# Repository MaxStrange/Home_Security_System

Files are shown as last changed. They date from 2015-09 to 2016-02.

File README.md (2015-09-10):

# Home_Security_System
A security system for my home!

This is a security system I am making for my home. It will consist of several wireless Arduino Pro Minis acting as sensor nodes
using PIR motion sensors, magnetic switches, a siren, microphones, and maybe an RF ID reader as the arm/disarm mechanism.

Uses tmrh20's fork of ManiacBug's NRF library for the wireless mechanisms (since XBee is so super expensive).

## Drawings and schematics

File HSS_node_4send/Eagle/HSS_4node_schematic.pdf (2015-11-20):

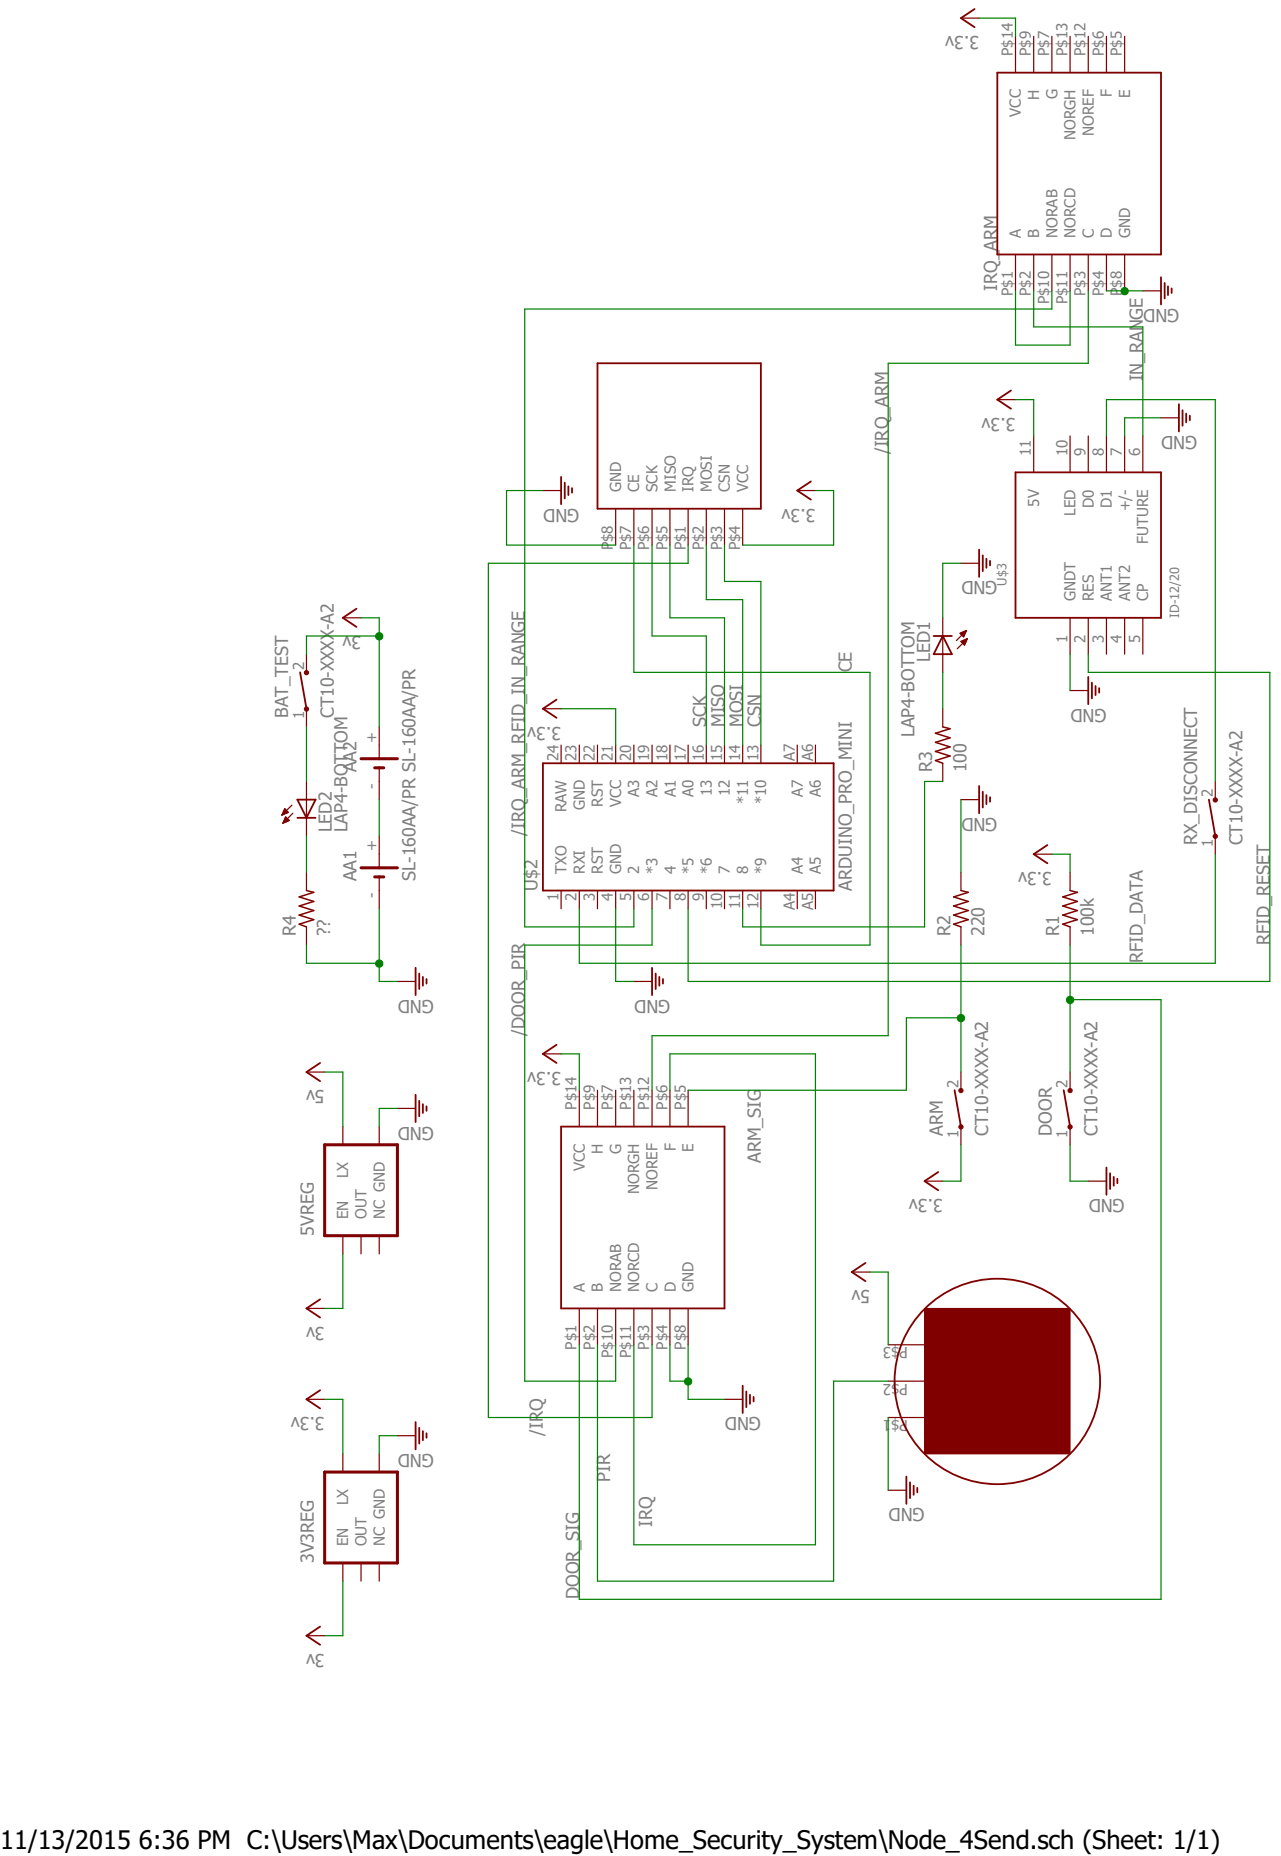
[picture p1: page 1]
8 11 *9 12 *10 13 *11 14 12 15 13 16 A0 17 A1 18 A2 19 A3 20 GND; 1 VCC 21 A7 A7 A6 A6 A4 A4 A5 A5 U$3 GNDT 1 RES; 2 ANT1; 3 ANT2; 5 FUTURE

F P$6 NOREF P$12 NORGH P$13 G P$7 H P$9 VCC P$14 LED2 R4 BAT_TEST 1 2 R3 LED1 RX_DISCONNECT 1 2 DOOR_SIG CE SCK MISO MOSI CSN /IRQ IRQ PIR ARM_SIG /DOOR_PIR /IRQ_ARM IRQ_ARM IN_RANGE /IRQ_ARM_RFID_IN_RANGE RFID_DATA RFID_RESET

A P$1 B P$2 NORAB P$10 NORCD P$11 C P$3 D P$4 GND P$8 E P$5

9 LED 10 5V 11 ARM 1 2 DOOR 1 2 R2R1

F P$6 NOREF P$12 NORGH P$13 G P$7 H P$9 VCC P$14 VCC P$4 CSN P$3 MOSI P$2 IRQ P$1 MISO P$5 SCK P$6 CE P$7 GND P$8

11/13/2015 6:36 PM C:\Users\Max\Documents\eagle\Home_Security_System\Node_4Send.sch (Sheet: 1/1) SL⁻160AA/PR SL⁻160AA/PR

4 GND 23 RAW 24 RST

3 RST 22 RXI 2 TXO

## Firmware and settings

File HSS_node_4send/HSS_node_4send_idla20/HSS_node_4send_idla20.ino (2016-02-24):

/**
This is the 4send node. It is the node responsible for sending
the arm/disarm signal to the rest of the nodes. It also has
sensor (PIR and magnetic switch) through a NOR gate (so they
are active low).

It sleeps until an interrupt on pin 2 wakes it. Pin 2 could
be one of three things: the RFID has sensed a tag in range,
the nRF has sent an IRQ (probably because it received a 
signal), and/or the arm button was pushed. It first checks
its nRF module to see if that was what woke it. If it was, and
it received an arm signal (which is impossible until I get
a raspberry pi online), it arms itself (sets up an interrupt
from the sensors on pin 3) and goes back to sleep. Whether or
not it was the nRF that woke it, it also checks to see if
the RFID module has a card waiting to be read. If it does,
it reads the card and, if the card is one of the known ones,
it disarms itself and broadcasts the disarm signal. If neither
of these things was what woke it from sleep, it must have
been the arm signal. If it was, it broadcasts the arm signal
and arms itself (puts the sensor interrupt on pin 3) and
goes back to sleep.

Once armed, it sleeps until woken up by either an interrupt
on pin 2 (in which case, see above) or an interrupt on pin 3,
in which case it has sensed an intruder and it therefore sends
a threat signal to the accumulator node. Once it has sent
this message and it is reasonably sure it has been heard, it
will not send its threat signal again until disarmed and 
re-armed or a power cycle happens.
*/
#include <avr/interrupt.h>
#include <avr/power.h>
#include <avr/sleep.h>
#include <avr/io.h>
#include <SPI.h>
#include "RF24.h"

/**Constants**/
const unsigned int SECONDS_TO_CLEAR_AREA = 30;//The number of seconds the system will give people to clear the area before arming after the arm button has been pushed
const unsigned int TIMES_TO_SEND = 6;//The number of times to try to send a signal before giving up
const unsigned int MAX_TIMES_TO_SEND_SIGNAL = 15;//The maximum number of times to send the threat signal to the accumulator per disarm/arm cycle
const uint16_t THREAT_SIGNAL = 0x1BA0;
const uint16_t DISARM_SIGNAL = 0x1151;
const uint16_t ARM_SIGNAL = 0x1221;

/**Pin declarations**/
const int SENSORS = 3;//Mag switch NOR'd with a PIR signal
const int LED = 8;
const int RADIO_PIN_1 = 9;
const int RADIO_PIN_2 = 10;

/**Radio code**/
RF24 radio(RADIO_PIN_1, RADIO_PIN_2);
//Accumulator and four other nodes. Node 4send is the arm/disarm node. The fifth is a private channel from node4 to accmltr
byte node_ids[][6] = { "cmltr", "1send", "2send", "3send", "4send" , "5send" };

/**RFID code**/
const int KEY_LENGTH = 16;
char key_a[KEY_LENGTH] = { 63, 100, 94, 230, 166, 102, 230, 76, 102, 166, 201, 201, 202, 214, 242, 0 };
char key_b[KEY_LENGTH] = { 63, 100, 94, 230, 166, 102, 166, 76, 153, 166, 76, 153, 202, 214, 242, 0 };
char key_c[KEY_LENGTH] = { 63, 100, 94, 230, 166, 166, 204, 151, 204, 201, 62, 234, 202, 214, 242, 0 };
char incoming_key[KEY_LENGTH] = { 0,0,0,0,0,0,0,0,0,0,0,0,0,0,0,0 };
String input_string = "";

/**State**/
volatile boolean disarm_flag = false;
volatile boolean rfid_flag = false;
volatile boolean arm_switch_flag = false;
volatile boolean arm_signal_heard_flag = false;
volatile boolean system_is_armed = false;
volatile unsigned int sent_signal_times = 0;//Number of times this node has sent the threat signal to the accumulator 
unsigned int arm_button_held_down_count = 0;//Duration that the arm button has been held for

void setup(void)
{  
  /**Pins**/
  pinMode(SENSORS, INPUT);
  pinMode(LED, OUTPUT);
  
  /**Radio**/
  radio.begin();
  radio.setRetries(15, 15);//Retry 15 times with a delay of 15 microseconds between attempts
  radio.openWritingPipe(node_ids[4]);//open up a broadcasting pipe - all other nodes listen to this pipe
  
  /**RFID**/
  Serial.begin(9600);
  input_string.reserve(20);
}

void loop(void)
{
  serialEvent();
  
  if (rfid_flag)
  {//check if there is rfid data waiting on serial
    Serial.println("RFID flag.");
    if (check_rfid())
    {
      disarm_flag = true;
      arm_switch_flag = false;
      arm_button_held_down_count = 0;
      Serial.println("known key");
    }
    //now flush the rfid so that it doesn't contain any leftover data
    input_string = "";
    Serial.println("Input buffer flushed.");
    rfid_flag = false;//clear the flag
    Serial.println("RFID flag cleared.");
  }
  
  if (disarm_flag)
  {//disarm the system - broadcast the disarm signal and then disarm
    Serial.println("Disarm flag.");
    disarm_system();
    disarm_flag = false;//clear the flag
    digitalWrite(LED, HIGH); 
    Serial.println("Disarm flag cleared.");
  }
  
  if (arm_switch_flag)
  {//arm the system - broadcast the arm signal and then arm yourself
    Serial.println("Arm switch flag.");
    arm_switch_flag = false;//clear the flag
    
    if (check_rfid())
    {
      Serial.println("Key is present.");
    }
    else
    {
      if (!system_is_armed)
        arm_button_held_down_count++;
        
      Serial.print("Arm button held: "); Serial.println(arm_button_held_down_count);
      
      if ((arm_button_held_down_count >= 5) && (!system_is_armed))
        arm_system();
    }
    
    Serial.println("Arm switch flag cleared.");
  }
  
  if (arm_signal_heard_flag)
  {//arm this particular node - the system has been broadcasted to already by the rPi
    Serial.println("Arm signal heard flag.");
    arm_signal_heard_flag = false;//clear the flag
    arm_self();
    Serial.println("Arm signal heard flag cleared.");
  }
  
  //All done with work that needed to be done. Put the RFID/nRF/Arm_switch interrupt back on and go to sleep.
  Serial.println("Sleep.");
  delay(500);
  digitalWrite(LED, LOW);
  attachInterrupt(0, arm_disarm_ISR, LOW);
  go_to_sleep();
}

void arm_disarm_ISR(void)
{
  detachInterrupt(0);//Don't interrupt again until flags have been dealt with - this should also serve to debounce the arm switch
  detachInterrupt(1);
  
  /**First, make sure to check the RFID**/
  rfid_flag = true;
  
  /**Now check the radio**/
  bool tx, fail, rx = false;
  radio.whatHappened(tx, fail, rx);
    
  /**If rx, get what we received**/
  uint8_t reading_pipe_number;
  if (rx && radio.available(&reading_pipe_number))
  {
    uint16_t signal;
    radio.read(&signal, sizeof(uint16_t));
    
    if (signal == DISARM_SIGNAL)
      disarm_flag = true;
    else if (signal == ARM_SIGNAL)
      arm_signal_heard_flag = true;
  }
  
  /**If not rx, was it the radio? 
  If so, don't care. But if it wasn't, 
  then it MIGHT have been the arm switch.**/
  if (!fail && !tx)
    arm_switch_flag = true;//if it wasn't the software serial, it was the arm switch - check that later
}

void sensor_ISR(void)
{
  if (sent_signal_times < MAX_TIMES_TO_SEND_SIGNAL)
  {
    detachInterrupt(0);
    detachInterrupt(1);
    Serial.println("sensor detected something. Sending threat.");
    //If this ISR is fired, it is because we are armed and either the mag switch is open or the PIR saw something
    radio.stopListening();
    radio.openWritingPipe(node_ids[5]);//open the private channel between this node and the accumulator
    if (write_to_radio(&THREAT_SIGNAL, sizeof(uint16_t)))
      sent_signal_times++;
    radio.openWritingPipe(node_ids[4]);//reopen the broadcast channel - close the other channel
    attachInterrupt(0, arm_disarm_ISR, LOW);
    attachInterrupt(1, sensor_ISR, LOW);
  }
  else
  {//we have already bugged the accumulator enough - it probably heard us by now, so let's just stop trying
    detachInterrupt(1);
  }
}

void arm_self(void)
{
  Serial.println("Arm self.");
  
  system_is_armed = true;
  attachInterrupt(1, sensor_ISR, LOW);//arm yourself too
}

void arm_system(void)
{
  Serial.println("Arm system.");
  arm_button_held_down_count = 0;
  digitalWrite(LED, HIGH); 
  
  /*Delay for how ever many seconds, checking for a key every second*/
  boolean do_not_arm = false;
  for (int i = SECONDS_TO_CLEAR_AREA; i > 0; i--)
  {
    Serial.print("Countdown: "); Serial.println(i);
    delay(1000);
  }
  
  if (!do_not_arm)
  {
    broadcast_signal(ARM_SIGNAL);
    arm_self();
  }
}

void disarm_system(void)
{
  detachInterrupt(1);//detach sensor ISR
  Serial.println("Disarm system.");
  broadcast_signal(DISARM_SIGNAL);
  system_is_armed = false;
  sent_signal_times = 0;
}

void broadcast_signal(uint16_t signal)
{
  Serial.println("Broadcast signal.");
  radio.stopListening();
  write_to_radio(&signal, sizeof(uint16_t));
}

void go_to_sleep(void)
{
  set_sleep_mode(SLEEP_MODE_IDLE);
  //set_sleep_mode(SLEEP_MODE_STANDBY);//standby works - but no deeper - only takes 6 clock cycles to boot back up
  sleep_enable();
  sleep_mode();
}

boolean write_to_radio(const void * to_write, uint8_t len)
{
  Serial.println("Write to radio.");
  
  for (int i = 0; i < TIMES_TO_SEND; i++)
  {
    Serial.print("Write: "); Serial.println(i);
    if (radio.write(to_write, len))//This is the line that is buggy. It hangs here eventually, but only when trying to disarm the system. And not necessarily on the first call to this from the disarm.
    {
      return true;
    }
    
    delay(10);
  }
  
  Serial.println("Returning false.");
  return false;
}

void serialEvent()
{
   while (Serial.available())
   {
     char inChar = (char)Serial.read();  
     input_string += inChar;
   }
   
   input_string.toCharArray(incoming_key, KEY_LENGTH);
}

boolean check_rfid()
{
   for (int i = 0; i < KEY_LENGTH; i++)
   {
     if ((incoming_key[i] != key_a[i]) && (incoming_key[i] != key_b[i]) && (incoming_key[i] != key_c[i]))
     {
       return false;
     }
   }
   
   return true;
}

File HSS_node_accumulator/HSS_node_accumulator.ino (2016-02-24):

/**
This is the accumulator sketch. It is the node that is responsible for sounding the alarm if the right sequence of events
happen as reported by the other sensor nodes. To save money and space, it is also a pir/switch sensor node.

It sounds the alarm if it receives a signal from two different nodes (including possibly itself). If it receives
a signal from a node, it enters the alert mode, whereupon it starts a countdown. If, within that countdown, it receives
a second signal (not from the same node), it enters intruder_detected mode and sounds the alarm. If it doesn't receive
the second signal within the alotted time, it resets back to all_clear mode.

If it enters intruder_detected mode, it will sound the alarm for several seconds, and wait for the disarm signal to come.
If it never gets the disarm signal, it eventually resets to all_clear.
*/
#include <avr/interrupt.h>
#include <avr/power.h>
#include <avr/sleep.h>
#include <avr/io.h>
#include <SPI.h>
#include "RF24.h"

/**Typedefs**/
typedef enum { ALL_CLEAR_MODE, ALERT_MODE, INTRUDER_DETECTED_MODE } alert_level_type;

/**Constants**/
const unsigned long ALARM_COUNTDOWN = 30000;//30,000 milliseconds (30 seconds)//The time the alarm sounds for
const unsigned long INTRUDER_COUNTDOWN = 20000;//20,000 milliseconds (20 seconds)//The amount of time to wait for a second threat signal before reset
const uint16_t THREAT_SIGNAL = 0x1BA0;
const uint16_t DISARM_SIGNAL = 0x1151;
const uint16_t ARM_SIGNAL = 0x1221;
const unsigned int NUMBER_OF_NODES = 5;//Number of nodes in the system including this one
const unsigned int TIME_TO_DISARM = 10000;//10,000 milliseconds (10 seconds)//The time you have to disarm the system before alarm

/**Pin declarations**/
const int SENSORS = 3;//PIR and Mag switch through a NOR gate - so LOW when bad guy detected
const int SPEAKER = 8;
const int RADIO_PIN_1 = 9;
const int RADIO_PIN_2 = 10;

/**Radio code**/
RF24 radio(RADIO_PIN_1, RADIO_PIN_2);
//Accumulator and four other nodes. Node 4send is the arm/disarm node. The fifth is a private channel from node4 to accmltr
byte node_ids[][6] = { "cmltr", "1send", "2send", "3send", "4send" , "5send" };

/**State**/
volatile boolean system_armed = false;
volatile alert_level_type danger_level = ALL_CLEAR_MODE;
volatile unsigned long countdown_timer = 0;
volatile boolean alert_from_node[] = { false, false, false, false, false };//Array of alerts from nodes in the system - node 0 is this node.
volatile boolean disarm_flag = false;
volatile boolean arm_system_flag = false;
boolean alarm_sounding = false;

void setup(void)
{
  /**Pins**/
  pinMode(SENSORS, INPUT);
  pinMode(SPEAKER, OUTPUT);
  
  /**Radio**/
  radio.begin();
  radio.setRetries(15, 15);//Retry 15 times with a delay of 15 microseconds between attempts
  radio.openReadingPipe(1, node_ids[1]);
  radio.openReadingPipe(2, node_ids[2]);
  radio.openReadingPipe(3, node_ids[3]);
  radio.openReadingPipe(4, node_ids[4]);//arm/disarm node broadcast channel
  radio.openReadingPipe(5, node_ids[5]);//private channel to arm/disarm node
  radio.startListening();
  
  attachInterrupt(0, check_messages_ISR, LOW);//Attach an interrupt on a LOW signal on Pin 2
  
  Serial.begin(115200);
}

void loop(void)
{ 
  digitalWrite(SPEAKER, HIGH);
  
  /*Go through the flags and deal with them*/
  if (disarm_flag)
  {
    disarm_flag = false;
    disarm();
  }
    
  if (arm_system_flag)
  {
    arm_system_flag = false;
    system_armed = true;
    attachInterrupt(1, sensor_ISR, LOW);
  }
  
  if (! system_armed)
  {
    Serial.println("System not armed, so going to sleep.");
    delay(1000);
    //Just go to sleep until the system is armed
    set_sleep_mode(SLEEP_MODE_PWR_DOWN);
    sleep_enable();
    sleep_mode();
  }
  
  adjust_threat_level();
  
  /**Manipulate countdown timer and adjust mode accordingly**/
  if (countdown_timer > ALARM_COUNTDOWN)
  {//Timer has wrapped around for some reason, reset it.
    Serial.println("Countdown timer has wrapped around. This shouldn't have happened.");
    Serial.print("Timer: "); Serial.println(countdown_timer);
    countdown_timer = 0;
  }
  else if (countdown_timer > 0)
  {
    for (int i = 0; i < 5; i++)
    {
      Serial.print("Node "); Serial.print(i); Serial.print(" "); Serial.println(alert_from_node[i] ? "true" : "false");
    }
  
    Serial.print("Counting down: "); Serial.println(countdown_timer);
    countdown_timer -= 1000;
  }
  else if (! (disarm_flag || arm_system_flag) )//only enter this block if there are no flags to check
  {
    Serial.println("Resetting node information.");
    digitalWrite(SPEAKER, HIGH);//stop sounding the alarm
    alarm_sounding = false;
    countdown_timer = 0;
    danger_level = ALL_CLEAR_MODE;
    reset_nodes();
    
    Serial.println("All clear, so going back to sleep.");
    
    if (system_armed)
    {
      attachInterrupt(1, sensor_ISR, LOW);
    }
    delay(1000);
    
    //when in all clear mode, go to sleep
    set_sleep_mode(SLEEP_MODE_PWR_DOWN);
    sleep_enable();
    sleep_mode();
  }
  delay(1000);
}

void sensor_ISR(void)
{
  detachInterrupt(1);//Now that we have seen something with this node, don't bother sensing any more until we get disarmed.
  Serial.println("sensor tripped.");
  if (alert_from_node[0])
  {
    return;//this node is already on alert - this is not new information
  }
  else
  {
    alert_from_node[0] = true;
  }
}
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

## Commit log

2015-09-04 Got a headless version of the getting started example working
    Got a headless version of the getting started nRF code working. Except
    it isn't *quite* headless yet. It works headless, but the code still
    contains some prints (which aren't necessary to the working of the code,
    but are useful for debugging). Next step is to get rid of the print
    statements and be completely headless. Then on to getting the PIR sensor
    working wirelessly.
    [PIR_sensor_test_pro_mini.fzz, nRF24l01p_pro_mini_test.fzz, nRF24l01p_pro_mini_test_with_PIR_tx.fzz]
2015-09-04 Got a headless PIR sensor working with two LEDS
    Also got the beginnings of a headless PIR sensor working wirelessly.
    [nRF24l01p_pro_mini_test_with_PIR_tx.fzz]
2015-09-04 Got the wireless PIR sensor working!
    PIR now senses motion on one Arduino and sends its current state to
    another which then responds by lighting an appropriate LED (RED for
    intruder alert, GREEN for all clear).
    [nRF24l01p_pro_mini_test.fzz, nRF24l01p_pro_mini_test_with_PIR_rx.fzz, nRF24l01p_pro_mini_test_with_PIR_tx.fzz]
2015-09-05 Got the PIR working with interrupts rather than with polling
    Also began work on getting the Arduino to go to sleep and to wake up
    whenever a signal from the PIR wakes it. Unfortunately, need to wait on
    some hardware...
    [PIR_sensor_test_interrupt.fzz, PIR_sensor_test_interrupt_and_sleep.fzz]
2015-09-08 Got a size three node topology working
    [mag_test.fzz, nRF24l01p_pro_mini_test_with_mag_rx.fzz, nRF24l01p_three_node_test_receiver.fzz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]
2015-09-08 Got the three nodes all talking to each other
    Also restructured the directory layout. All nRF tests are now in an nRF
    test folder inside the main project folder.
    [nRF24l01p_pro_mini_test.fzz, nRF24l01p_pro_mini_test_with_PIR_rx.fzz, nRF24l01p_pro_mini_test_with_PIR_tx.fzz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]
2015-09-10 Ported all the nRF tests to a newer, maintained lib
    Also added a simple microphone module test
    [nRF24l01p_uno_test_with_PIR_rx.fzz, nRF_interrupt_test.fzz, nRF_pro_mini_test.fzz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]
2015-09-10 Got the receiver to go to sleep when not receiving
    [three_node_receiver_sleep.fzz]
2015-09-14 Initial attempt at v0.1 accumulator sketch
    Also got a NOR gate test sketch written up.
    [NOR_gate_test.fzz, accumulator_0_1.fzz, sender.fzz]
2015-09-15 Wrote the accumulator node version 1.0
    Also the 1send node and an RFID test.
    [HSS_node_1send.fzz, HSS_node_accumulator.fzz, accumulator_0_2.fzz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]
2015-09-15 Wrote tests for the RFID module
    Also wrote the introductory comment to the HSS_node_4send (the
    arm/disarm node).
    [HSS_node_4send.fzz, HSS_node_accumulator.fzz]
2015-09-16 Finished first stab at 1.0 for each node
    Next need to build tests, then build the circuits and run them to make
    sure everything is ready for prime time!
    [HSS_node_1send.fzz, HSS_node_2send.fzz, HSS_node_3send.fzz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]
2015-10-03 Radios now try to send several times until they do it successfully
    Before, they would just fire and ignore the result. This should help
    make the cheap, glitchy radios much more reliable.
    Also prepared some of the code for the raspberry pi, which will also be
    able to arm and disarm the system.
    [HSS_node_1send.fzz, HSS_node_2send.fzz, HSS_node_4send.fzz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]
2015-10-05 Changed the 4send node
    Now it wakes up upon hearing the arm button, and checks its software
    serial to see if there are keys to be read.
    [HSS_node_4send.fzz, HSS_node_4send_v0_1.fzz, relay_test.fzz]
2015-10-07 Trying to fix 4send's freezing problem
    The code as is works perfectly, except that it eventually freezes
    (sooner or later). Obviously, not ideal. Checking it in to source
    control so that I can have a fall back if changing it breaks it more.
    [HSS_node_4send.fzz]
2015-10-11 Got rid of the microphones, made a no_RFID version of the arm/disarm node, and made significant changes to accumulator
2015-10-12 Modified the Fritzing diagrams to reflect the removal of microphones
    [HSS_node_1send.fzz, HSS_node_2send.fzz]
2015-10-12 Significant changes to accumulator
    This version of the accumulator is significantly more stable than
    previous versions. Still need to make sure the speaker is low when
    supposed to be low and high when supposed to be high.
    Also the circuit seems to have something wrong with it - the PIR works
    fine, but using the door switch causes it to freeze, even though there
    is no difference in the code (both are on pin 3, low signal and are
    treated identically - in fact, the Arduino can't even tell the
    difference).
    [HSS_node_3send.ino, HSS_node_accumulator.ino]
2015-10-12 Accumulator now outputs the right signal to the speaker
    Now need to figure out why it is not disarming, why it is not getting
    sensor info from the 4send node, and why it seems to ignore other nodes
    whenever 3send is around (it only listens to 3send).
2015-10-13 Fixed bug where the accumulator was not hearing the private channel to 4send
    [HSS_node_1send.ino, HSS_node_2send.ino, HSS_node_3send.ino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]
2015-10-13 Fixed bug where the accumulator couldn't hear signals while counting down (including the disarm signal)
    [HSS_node_4send_no_RFID.ino, HSS_node_accumulator.ino]
2015-10-13 First stable version!
    Hurray!
    Every node can arm and disarm, sense motion, and send their signals
    reliably!
    Known issues still to be tracked down:
    -The arm/disarm node seems to freeze eventually. A hack is to reset it
    every so often, and I will do this. But I need to figure out why it is
    freezing so I can get at the root of the matter.
    -The arm/disarm node needs to be updated with a new RFID reader which
    can trigger an interrupt based on the presence of a card to scan and
    which will then communicate through the RX pin on the Arduino.
    -The accumulator node freezes when its magnetic switch is open.
    [HSS_node_2send.ino, HSS_node_accumulator.ino]
2015-11-09 Added a draft that should work with the new RFID reader
    Also made a schematic for 4send.
    [Node_4Send.sch]
2015-11-10 Removed some of the eagle files
    Just left the main schematic
    [Node_4Send.sch]
2015-11-10 Using pdf for schematics now
    [Node_4Send.sch]
2015-11-12 Finished the schematic for 4send
2015-11-13 Added LED to 4send
    Now it should blink an LED when the user successfully disarms the
    system.
2016-02-20 Minor modifications and bug fixes
    [HSS_node_4send.ino, HSS_node_4send_idla20.ino, HSS_node_4send_no_RFID.ino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]
